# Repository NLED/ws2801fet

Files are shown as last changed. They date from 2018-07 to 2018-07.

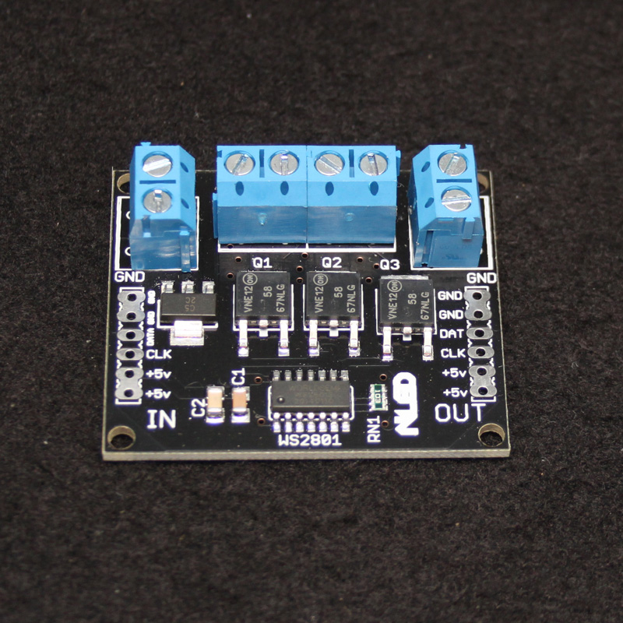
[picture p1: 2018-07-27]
nled-ws2801-fet-v1b.jpg

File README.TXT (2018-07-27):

THERE IS NO WARRANTY FOR THE PROGRAM, TO THE EXTENT PERMITTED BY APPLICABLE LAW. 
EXCEPT WHEN OTHERWISE STATED IN WRITING THE COPYRIGHT HOLDERS AND/OR OTHER PARTIES 
PROVIDE THE PROGRAM “AS IS” WITHOUT WARRANTY OF ANY KIND, EITHER EXPRESSED OR IMPLIED,
INCLUDING, BUT NOT LIMITED TO, THE IMPLIED WARRANTIES OF MERCHANTABILITY AND FITNESS 
FOR A PARTICULAR PURPOSE. THE ENTIRE RISK AS TO THE QUALITY AND PERFORMANCE OF THE 
PROGRAM IS WITH YOU. SHOULD THE PROGRAM PROVE DEFECTIVE, YOU ASSUME THE COST OF ALL 
NECESSARY SERVICING, REPAIR OR CORRECTION.

 Original Author: Jeffrey Nygaard
 Company: Northern Lights Electronic Design, LLC
 Date: July 26, 2018
 Contact: JNygaard@NLEDshop.com
 Copyright© 2018 by Northern Lights Electronic Design, LLC. All Rights Reserved
 
;=============          www.NLEDShop.com/ws2801fet          ============
;=============     www.NorthernLightsElectronicDesign.com       ============

This work is licensed under a Attribution-NonCommercial 4.0 International (CC BY-NC 4.0)
https://creativecommons.org/licenses/by-nc/4.0/legalcode

Free to use for personal use, but please attribute the original author.

Commercial licenses versions are available for a donation of any amount. Contact JNygaard@NLEDshop.com for details.

================================================================================================================

Ready-made devices are available for purchase, and large batch manufacturing of any device can be requested.
Please see the webpage www.NLEDShop.com/ws2801fet

NLED is available for custom design and manufacturing, please contact via phone or email to discuss your project.

================================================================================================================

Minimum Input Voltage: 5 volts
Maximum Input Voltage: 24 volts
Current Consumption: < 30mA estimated

BOM:
1x WS2801SO - SOIC-16
3x NTD5867NLT4G - TO-252-4 - N-Chan MOSFET, low RDS
1x 742C083103JP - 0603-ARV - quad 10Kohm network resistor
1x UA78M05CDCYR - SOT-223-4 - 5 volt regulator, many other equivalents
2x 50 ohm resistor - 0805 - for signal integrity
2x 10uF >=16vdc - 0805
1x 0.1uF >=6.3vdc - 0805
2x 2-pin 5.08 spaced screw terminal
1x 4-pin 5.08 spaced screw terminal

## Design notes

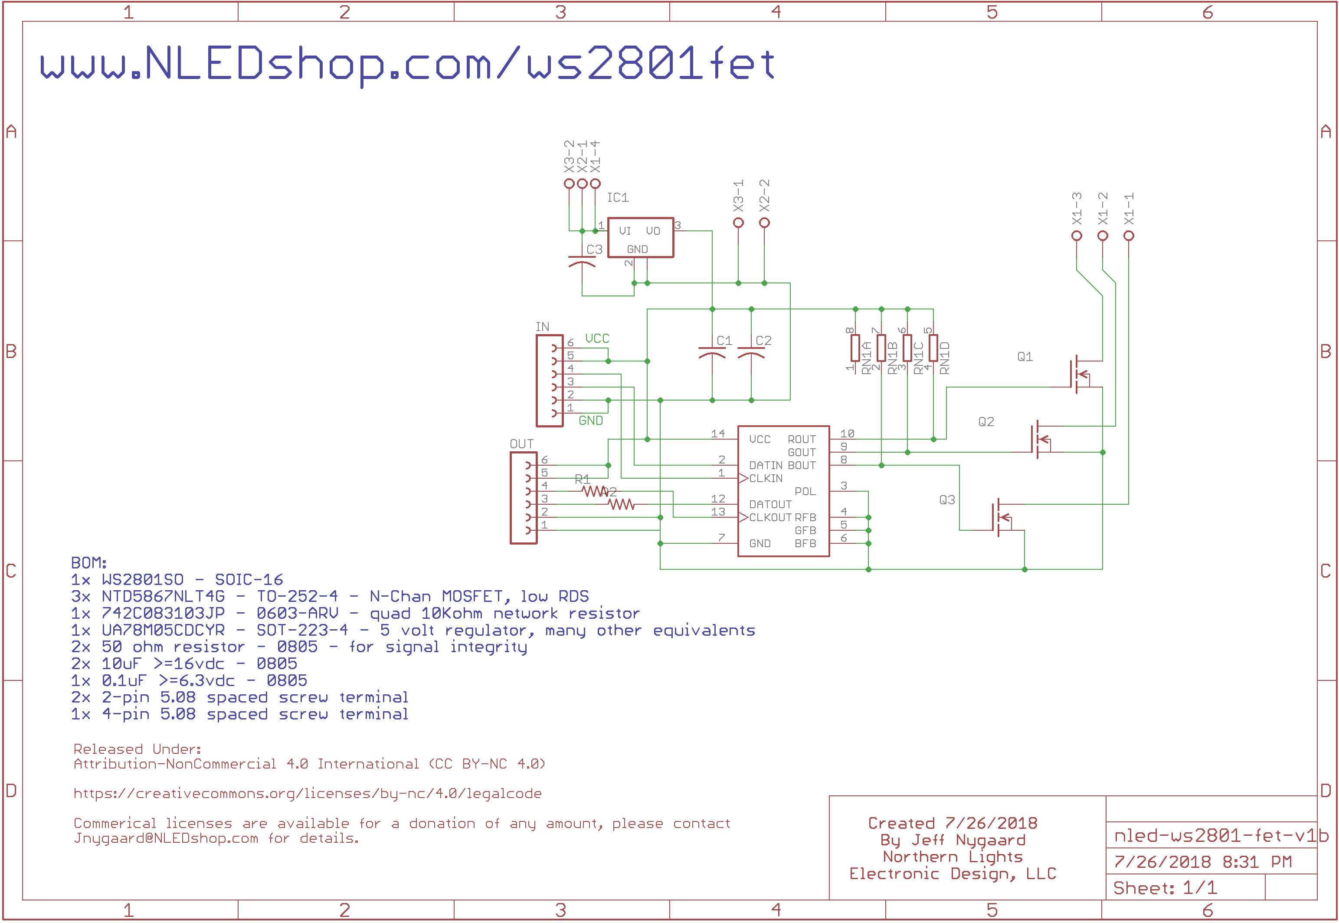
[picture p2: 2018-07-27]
ws2801-fet-schematic-v1b.png

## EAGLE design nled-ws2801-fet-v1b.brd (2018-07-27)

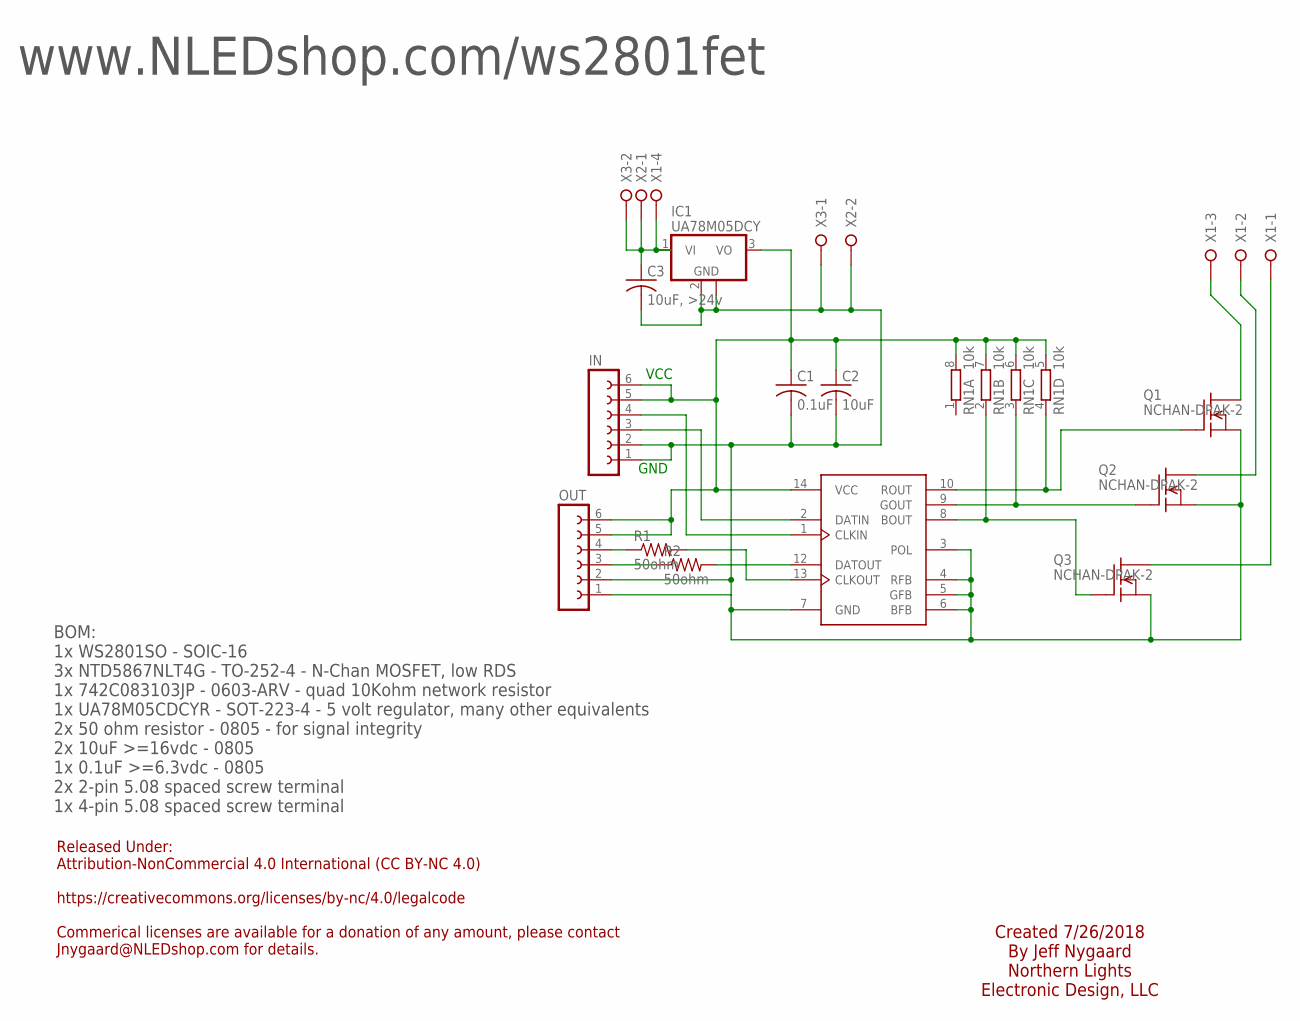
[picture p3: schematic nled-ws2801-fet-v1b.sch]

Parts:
C1: 0.1uF; C1206
C2: 10uF; C1206
C3: 10uF, >24v; C1206
IC1: UA78M05DCY; SOT223
IN: FE06-1; FE06
OUT: FE06-1; FE06
Q1, Q2, Q3: NCHAN-DPAK-2; DPAK-2PIN
R1, R2: 50ohm; M0805
RN1: 10k; 0603-ARV
WS2801: WS2801; SOP14
X1: W237-04P; W237-4P
X2, X3: W237-02P; W237-132

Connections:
GND: C1.2, C2.2, C3.2, IC1.2 (GND), IC1.4 (GND), IN.1, IN.2, OUT.1, OUT.2, Q1.3 (S), Q2.3 (S), Q3.3 (S), WS2801.3 (POL), WS2801.4 (RFB), WS2801.5 (GFB), WS2801.6 (BFB), WS2801.7 (GND), X2.2, X3.1
unnamed: Q1.1 (G), RN1.4 (1), WS2801.10 (ROUT)
unnamed: C3.1, IC1.1 (VI), X1.4, X2.1, X3.2
unnamed: Q2.2 (D), X1.2
unnamed: IN.4, WS2801.1 (CLKIN)
unnamed: Q2.1 (G), RN1.3 (1), WS2801.9 (GOUT)
unnamed: Q3.1 (G), RN1.2 (1), WS2801.8 (BOUT)
unnamed: Q3.2 (D), X1.1
unnamed: OUT.4, R1.1
unnamed: IN.3, WS2801.2 (DATIN)
unnamed: R1.2, WS2801.13 (CLKOUT)
unnamed: R2.2, WS2801.12 (DATOUT)
unnamed: Q1.2 (D), X1.3
unnamed: OUT.3, R2.1
VCC: C1.1, C2.1, IC1.3 (VO), IN.5, IN.6, OUT.5, OUT.6, RN1.5 (2), RN1.6 (2), RN1.7 (2), RN1.8 (2), WS2801.14 (VCC)

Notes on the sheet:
VCC
GND
Released Under: Attribution-NonCommercial 4.0 International (CC BY-NC 4.0) https://creativecommons.org/licenses/by-nc/4.0/legalcode Commerical licenses are available for a donation of any amount, please contact Jnygaard@NLEDshop.com for details.
Created 7/26/2018 By Jeff Nygaard Northern Lights Electronic Design, LLC
BOM: 1x WS2801SO - SOIC-16 3x NTD5867NLT4G - TO-252-4 - N-Chan MOSFET, low RDS 1x 742C083103JP - 0603-ARV - quad 10Kohm network resistor 1x UA78M05CDCYR - SOT-223-4 - 5 volt regulator, many other equivalents 2x 50 ohm resistor - 0805 - for signal integrity 2x 10uF >=16vdc - 0805 1x 0.1uF >=6.3vdc -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
www.NLEDshop.com/ws2801fet

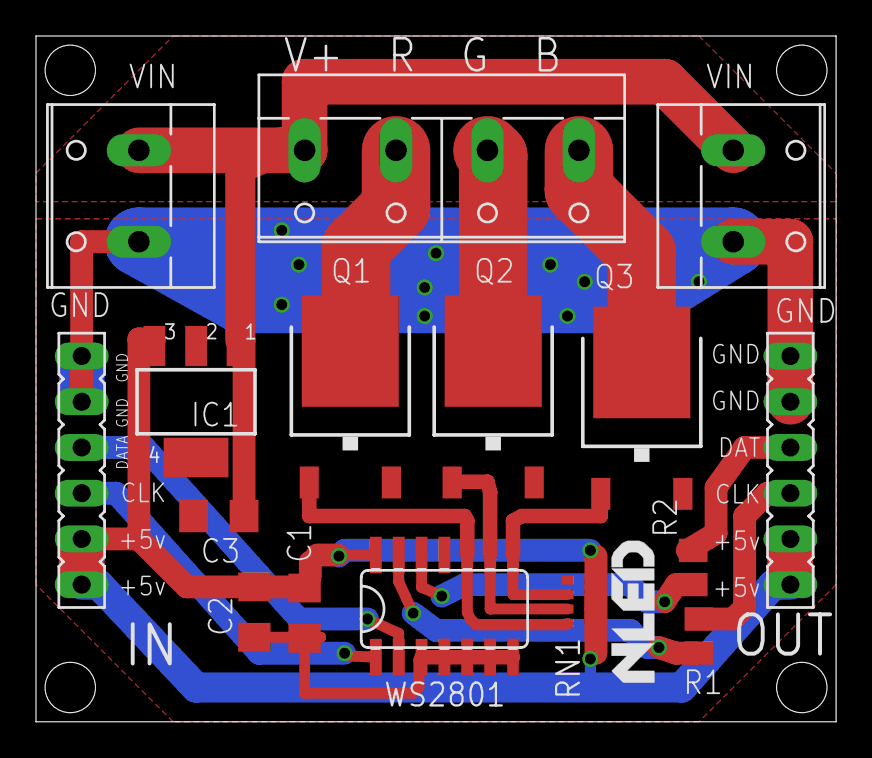
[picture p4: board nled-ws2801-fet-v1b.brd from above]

Board: 4 copper layers, 44.5 x 38.1 mm, 16 parts (0 on the bottom side), 15 nets.

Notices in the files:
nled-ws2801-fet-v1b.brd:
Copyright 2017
